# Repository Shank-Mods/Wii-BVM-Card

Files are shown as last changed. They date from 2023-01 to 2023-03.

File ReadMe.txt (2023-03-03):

These are the files I used to create the RVL-129X, a Wii on a BVM card. It is based on Martin's card. This project is essentially me craming his circuit into the corner, and adding pads to 1: solder the controller ports to and 2: bolt the Wii on. Consult his github for more info on the capabilities of the card portion of this project, as well as the software to program the Arduino.

Major Credits to Martin. Heres his github. He was awesome and super helpful. Could not have done this without him. Again, I just copied his homework and bolted a Wii to it. 
https://github.com/skumlos/bkm-129x-simple

It was a quick and dirty project not originally intended for public release. I am releaseing the files as is due to popular demand. It is cluttered, unoptimized, and made for my specific circumstances and my available parts. Sorry in advance.

Follow the Definitive Wii trimming gudie for information on how to trim and run the Wii. Standard trim. Run YPbPr and audio through shielded wire to the marked pads. SH is ground for shielding. Connect Controller lines to controller pads. 4 Layer Wii highly recommended. Leave the 1.8v LDO on the Wii. Ensure your Wii's settings have the resolution set to 480i if your PVMs are 15khz only. If your system is in 480p mode, you can disconnect the 3.3v-to-mode connection so set the system to composite and svideo mode, and run composite or luma to the Y line on the card for a usable black and white 15khz image that will let you navigate menus. 

The 129x card cannot pass audio through the slot, so audio comes out a 3.5mm jack and into the RCA jacks on the back. 

For voltage regulators, I purchased and bolted on an RVL-PSU. It contains all the voltage regulator rails the Wii needs. It is open source. You can assemble one yourself, use the open source design to integrate it onto this PCB, buy an RVL-PSU from CrazyGadget on the Bitbuilt forums, or design your own regulators if you are a pro. Do not use generic chinese voltage regulator boards, their power is not clean and will cause issues.

I included overkill voltage protection for every voltage rail of every controller port. This is because I plan to take it to Melee tournaments. The competitive Melee conroller modding scene has a huge problem with design and quality control of aftermarket and modded controllers. Many systems at tournaments have destroyed components caused by controllers overdrawing the voltage rails. These components are overkill, expensive, and tedious to solder. If these circumstances are not relevant to you, you can omit these components placed by the controller ports, and instead run 3.3v and 5v directly to the 3.3v and 5v pins of the controller ports with wires. 

Near the solder pads for the gamecube controller data wires are some diodes and filters. These are harvested from the lines connected to the data lines on the Wii motherboard. Diodes are for extra ESD protection. Filters can probably be jumpered over, but probably not best practice.

Resistors R2, R3, R4 and R5, along with R14, R15, R16 and R17 are not populated on this board. Csync pad is not used.

For screws I used the silver screws inside the wii, used mostly on the EMI shield.

For the fan and heatsink my usual setup: 35mm x 35mm x 7mm fan with 35mm x 35mm x 7mm heatsink, along with a 35x70mm copper plate. This setup has become the go-to in the portablizing community, and is used on many portables like the G-Wii. Use thermal paste between heatsink and copper plate. Use thermal pad between CPU/GPU and copper plate.

I didnt really plan where to put the USB port. I used a USB to micro SD card adapter, and mounted it to a GCC controller port with double sided foam adhesive tape. 

Theres an LDO (U5) that I didn't include on BOM because the replacement I purchased had a different pinout. I had to bodge it, but I added a jumper in case your LDO has that pinout. Check his github for specs on that part.

Included are 2 STLs that need to be printed. One is for mounting the Wii and the cooling system to the board. The other is the back plate. The back plate has 2 versions. V2 is the one I used. The extrusions for the screws are a little flimsy, so i made V3 to strengthen them. It should work and be stronger, but I never tested it so I included both. All 3d printed parts are mounted with silver scews from the Wii.

Order PCB with 1.6mm thickness. Its a 2 layer board, nothing special.

If you use this project, please credit me. Would love to see what people make with this. If you plan to monetize, please contact me.  

Troubleshooting tips I wish I knew:

Arduino must be programmed using the header. It WILL NOT WORK if programmed through the USB port on the arduino. 

Make sure U2 is being powered by U5 regulator. Different LDOs in that package have different pinouts. 

You can troubleshoot the signal chain by taking the Luma signal and skipping U2 and U1

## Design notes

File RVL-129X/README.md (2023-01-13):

A simplified version of the BKM-129X compatible board.

Should be able to be created at $25-30, with the ADG1611 being the most expensive component.

This requires an Arduino Nano v3 loaded with the latest BKM-129X-MCU code from https://github.com/skumlos/bkm-129x-mcu

For more information go to https://immerhax.com/?p=422

You are welcome to clone, produce and sell hardware based on this. Please keep changes and so on open source.

Cool kids give credit where due.

Thanks goes out to Nick Carney and Bob from RetroRGB for rigorious testing!

--------

Compatibility list and tested consoles (including issues):

PVM-9L2
- SNES (US region, CSYNC)
- Mega Drive 2 (EU region, 60 Hz modded with DFO for "true" 60 Hz, CSYNC)
- Master System 1 (EU region, 60 Hz modded with DFO for "true" 60 Hz, CSYNC)
- PC-Engine (White, with THS7374 external RGB amp, CSYNC)

BVM-D14
- Genesis 1 (60 Hz, CSYNC)

BVM-D9
- Nomad (60 Hz, Triple bypass modded, CSYNC)
- SNES (US region, CSYNC)
- Master System (60 Hz, sync issues like original 129X)
- TurboGrafx/PC-Engine (60 Hz, sync issues like original 129X)

---------

Board revision history:

D: Fix THS7374 filter bypass, move to Kicad 5

C: Rearranged some components for nicer layout

B: Added R29, R30, R31 to compensate for overbrightness

A: Changed R9 to 0 Ohm / jumper

---------

Copyright © 2020 Martin Hejnfelt <martin@hejnfelt.com>
This work is free. You can redistribute it and/or modify it under the
terms of the Do What The Fuck You Want To Public License, Version 2,
as published by Sam Hocevar. See the LICENSE file for more details.

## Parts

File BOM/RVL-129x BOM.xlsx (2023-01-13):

Resistors | Minimum | I ordered this many
75 ohm 1% 0603 | 4 | 20 | CR0603-FX-75R0ELF | https://www.mouser.com/ProductDetail/Bourns/CR0603-FX-75R0ELF?qs=Ody%252BWaR0NcEE9MIPBByqfg%3D%3D
100 ohm 0603 | 4 | 20 | CR0603-FX-1000ELF | https://www.mouser.com/ProductDetail/Bourns/CR0603-FX-1000ELF?qs=K5ddiUFZPT7prY7pGcr1LQ%3D%3D
150 ohm 1% 0603 | 7 | 20 | CR0603-FX-1500ELF | https://www.mouser.com/ProductDetail/Bourns/CR0603-FX-1500ELF?qs=e7cxVwPieupBDLrUX3Cc4g%3D%3D
4.7k 0603 | 2 | 20 | CR0603-FX-4701ELF | https://www.mouser.com/ProductDetail/Bourns/CR0603-FX-4701ELF?qs=CCIlxZRRv7jGwxSydcgiTA%3D%3D
10k 0603 | 4 | 20 | CR0603-FX-1002ELF | https://www.mouser.com/ProductDetail/Bourns/CR0603-FX-1002ELF?qs=K5ddiUFZPT6XHG0dQH96QA%3D%3D
100k 0603 | 5 | 20 | CR0603-FX-1003ELF | https://www.mouser.com/ProductDetail/Bourns/CR0603-FX-1003ELF?qs=K5ddiUFZPT49r0RoKWcKqg%3D%3D
20k | 8 | 20 | CR0603-FX-2002ELF | https://www.mouser.com/ProductDetail/Bourns/CR0603-FX-2002ELF?qs=zx2075yZkZIvZj%252BMy%2F3LPw%3D%3D
210k 0603 | 8 | 20 | CR0603-FX-2103ELF | https://www.mouser.com/ProductDetail/Bourns/CR0603-FX-2103ELF?qs=zx2075yZkZKSM3nxee360w%3D%3D
Capacitors
0.1uf 0805 | 9 | 12 | C0805C104K5RAC7411 | https://www.mouser.com/ProductDetail/KEMET/C0805C104K5RAC7411
1uf 0805 | 1 | 2 | 08055C105KAT4A | https://www.mouser.com/ProductDetail/KYOCERA-AVX/08055C105KAT4A
2.2uf 0805 | 1 | 2 | VJ0805V225MXJTW1BC | https://www.mouser.com/ProductDetail/Vishay-Vitramon/VJ0805V225MXJTW1BC
100uf 6.3x5.3,3 package | 3 | 5 | AVES107M16D16T-F | https://www.mouser.com/ProductDetail/Cornell-Dubilier-CDE/AVES107M16D16T-F
0.1uf 0603 (more than 5v) | 8 | 10 | C0603C104K5RAC3121 | https://www.mouser.com/ProductDetail/KEMET/C0603C104K5RAC3121
10uf 0603 (more than 5v) | 8 | 10 | 06036D106MAT2A | https://www.mouser.com/ProductDetail/KYOCERA-AVX/06036D106MAT2A?qs=SnLCPPi%2FUkQWQ97wPZ%2F8XA%3D%3D
ICs
THS7374 TSSOP-14_4.4x5mm_Pitch0.65mm | 1 | 2 | THS7374IPWR | https://www.mouser.com/ProductDetail/Texas-Instruments/THS7374IPWR?qs=qU0TI%2FZyA%252BxCw%252BZ%2FnXjpBw%3D%3D
ADG1611 TSSOP-16_4.4x5mm_Pitch0.65mm | 1 | 1 | DG1411EEQ-T1-GE4 | https://www.mouser.com/ProductDetail/Vishay-Siliconix/DG1411EEQ-T1-GE4?qs=AQlKX63v8RtOlhgumHRmnQ%3D%3D
74LVC125 TSSOP-14_4.4x5mm_Pitch0.65mm | 1 | 2 | 771-74LVC125APW-T | https://www.mouser.com/ProductDetail/Nexperia/74LVC125APW118?qs=me8TqzrmIYV8VAZOS5KVLw%3D%3D
DTC144EKA SC-59 | 1 | 3 | DTC144EKAT146 | https://www.mouser.com/ProductDetail/ROHM-Semiconductor/DTC144EKAT146?qs=4kLU8WoGk0s6Af1cWyUglg%3D%3D
TPS25221DRVT | 8 | 10 | TPS25221DRVT | https://www.mouser.com/ProductDetail/Texas-Instruments/TPS25221DRVT?qs=55YtniHzbhC2wJe7VYvGRA%3D%3D
Connector
PCN10A-64P-2.54DS(72) | 1 | 1 | PCN10A-64P-2.54DS(72) | https://www.mouser.com/ProductDetail/Hirose-Connector/PCN10A-64P-2.54DS72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
SJ-3524-SMT-TR | 1 | 2 | SJ-3524-SMT-TR
Other
Arduino Nano | 1 |  | What Martin's Github Says
*Yellow lines are for controller protection circuitry

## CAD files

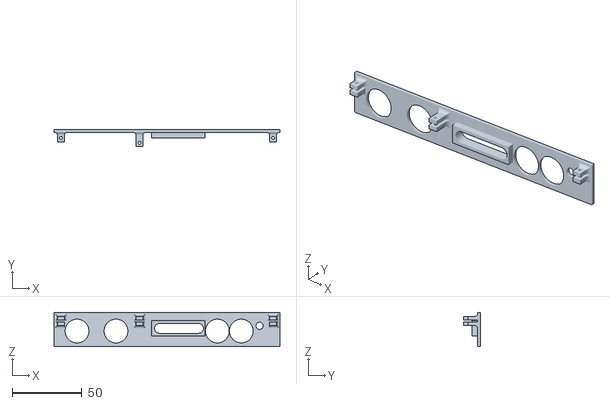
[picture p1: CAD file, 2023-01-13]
STLs/RVL-129xPlate v2 (tested).stl
161.5 x 12.0 x 24.5

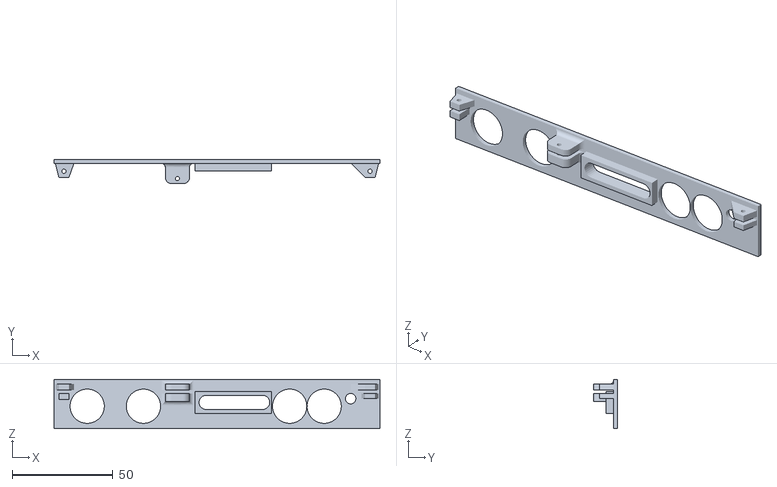
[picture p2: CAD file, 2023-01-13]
STLs/RVL-129xPlate v3 (improved but untested).stl
161.5 x 12.0 x 24.5

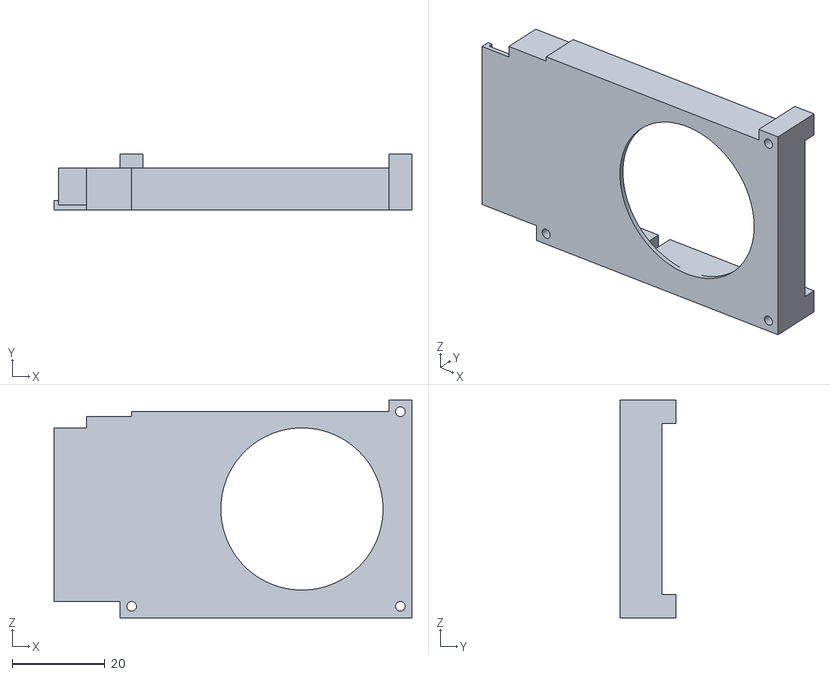
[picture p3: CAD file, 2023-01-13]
STLs/RVL129x-CoolingBracket_v2.stl
77.2 x 12.0 x 47.0

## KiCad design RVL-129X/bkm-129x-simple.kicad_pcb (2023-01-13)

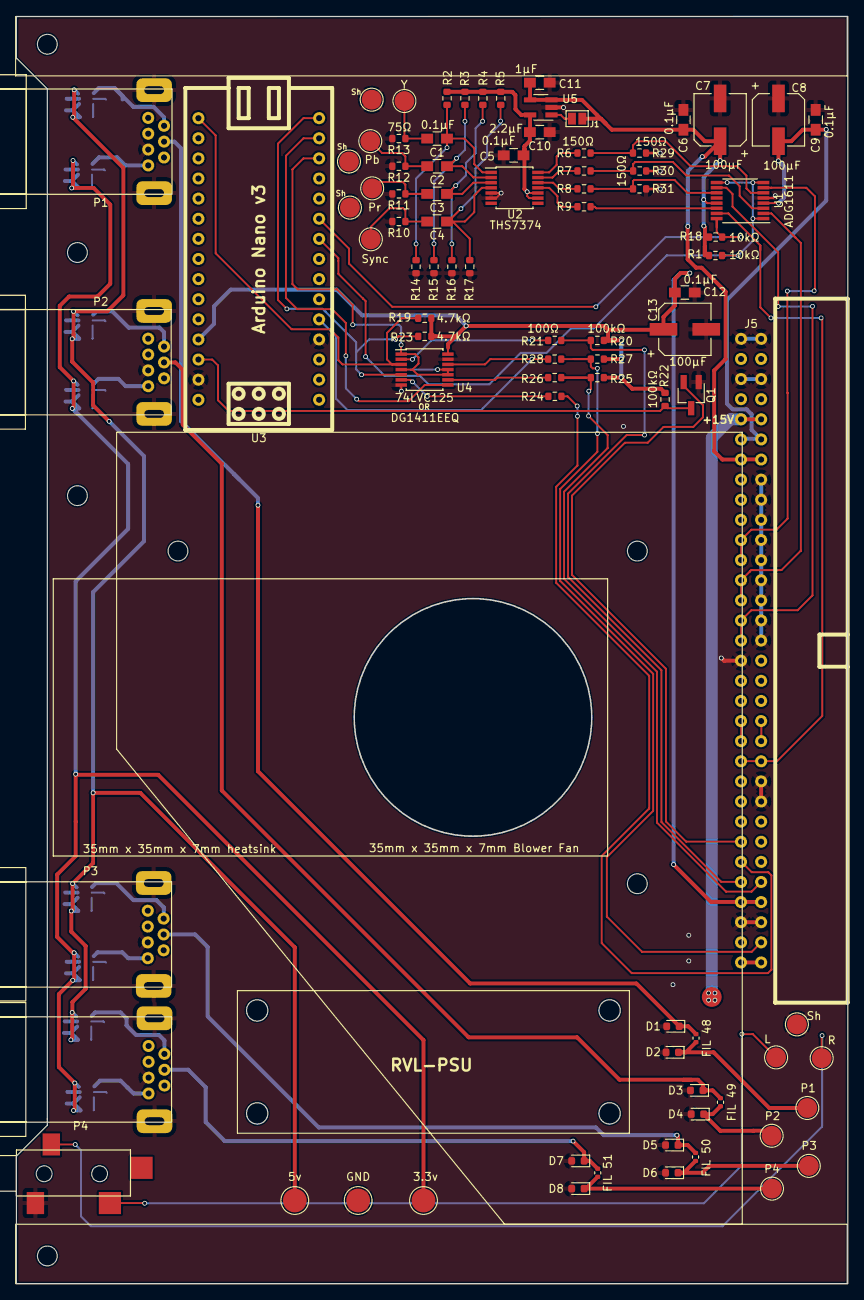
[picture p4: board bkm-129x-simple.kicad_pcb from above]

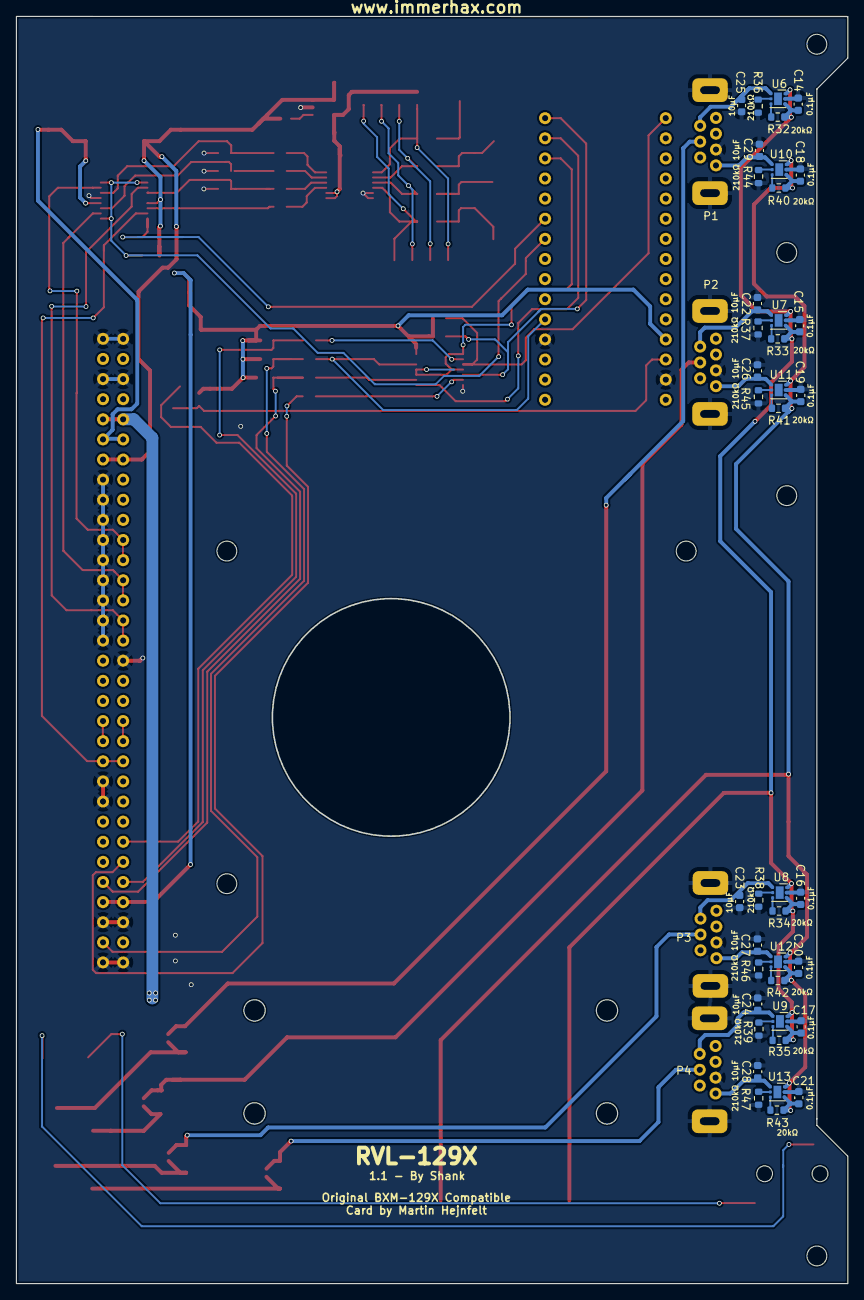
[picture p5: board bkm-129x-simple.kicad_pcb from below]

Board: 2 copper layers, 105.0 x 160.0 mm, 124 parts (40 on the bottom side), 71 nets.

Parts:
C1, C2, C3, C4, C5, C6, C9, C12: 0.1uF; C_0805_HandSoldering
C7, C8, C13: 100uF; CP_Elec_6.3x5.3
C10: 2.2uF; C_0805_HandSoldering
C11: 1uF; C_0805_HandSoldering
C14, C15, C16, C17, C18, C19, C20, C21, C22, C23, C24, C25, C26, C27, C28, C29: C; C_0603_1608Metric
CN1, CN2: GC_Ports; GCC Ports
D1, D2, D3, D4, D5, D6, D7, D8: D; D_0603_1608Metric
J1: SolderJumper-2_P1.3mm_Open_Pad1.0x1.5mm
J5: Conn_02x32_Row_Letter_Last; DIN-41612-64P
Q1: DTC144EKA; SC-59_Handsoldering
R1, R18: 10K; R_0603_1608Metric
R2, R3, R4, R5, R14, R15, R16, R17, R32, R33, R34, R35, R36, R37, R38, R39, R40, R41, R42, R43, R44, R45, R46, R47: R; R_0603_1608Metric
R6, R7, R8, R29, R30, R31: 150R; R_0603_1608Metric
R9: 0R; R_0603_1608Metric
R10, R11, R12, R13: 75R; R_0603_1608Metric
R19, R23: 4K7; R_0603_1608Metric
R20, R22, R25, R27: 100K; R_0603_1608Metric
R21, R24, R26, R28: 100R; R_0603_1608Metric
R48, R49, R50, R51: R; R_0402_1005Metric
TP1, TP2, TP3: TestPoint; TestPoint_Pad_D3.0mm
TP4, TP5, TP6, TP7, TP8, TP9, TP10, TP11, TP12, TP13, TP14, TP15, TP16, TP17: TestPoint; TestPoint_Pad_D2.5mm
U1: ADG1611; TSSOP-16_4.4x5mm_Pitch0.65mm
U2: THS7374; TSSOP-14_4.4x5mm_Pitch0.65mm
U3: arduino-nano-v3
U4: 74LVC125; TSSOP-14_4.4x5mm_Pitch0.65mm
U5: MIC3490-3.3; SOT-23-5_HandSoldering
U6, U7, U8, U9, U10, U11, U12, U13: TPS25221; WSON-6-1EP_2x2mm_P0.65mm_EP1x1.6mm
U14: PWP2_HeadphoneJackWithSwitch; HPJack

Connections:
3V3-P1: C29.1, CN1.7A (3.3v), U10.1 (OUT)
3V3-P2: C26.1, CN1.7B (3.3v), U11.1 (OUT)
3V3-P3: C27.1, CN2.7A (3.3v), U12.1 (OUT)
3V3-P4: C28.1, CN2.7B (3.3v), U13.1 (OUT)
3V3-PSU: C18.1, C19.1, C20.1, C21.1, R40.2, R41.2, R42.2, R43.2, TP1.1, U10.4 (EN), U10.6 (IN), U11.4 (EN), U11.6 (IN), U12.4 (EN), U12.6 (IN), U13.4 (EN), U13.6 (IN)
5V-P1: C25.1, CN1.1A (5v), U6.1 (OUT)
5V-P2: C22.1, CN1.1B (5v), U7.1 (OUT)
5V-P3: C23.1, CN2.1A (5v), U8.1 (OUT)
5V-P4: C24.1, CN2.1B (5v), U9.1 (OUT)
5V-PSU: C14.1, C15.1, C16.1, C17.1, R32.2, R33.2, R34.2, R35.2, TP2.1, U6.4 (EN), U6.6 (IN), U7.4 (EN), U7.6 (IN), U8.4 (EN), U8.6 (IN), U9.4 (EN), U9.6 (IN)
+3V3: C5.1, C10.1, R2.1, R3.1, R4.1, R5.1, U2.9 (BYPASS), U2.10 (VCC), U5.5 (VOUT)
+5VD: C12.1, C13.1, R19.2, R20.2, R22.1, R23.2, R25.2, R27.2, U3.27 (5V), U4.14 (VCC)
/MCU_SCK: R19.1, U3.16 (17/PB5/PCINT5/SCK), U4.3 (O)
/MCU_SLOT_ID: R28.1, U3.5 (32/PD2/INT0/PCINT18), U4.12 (D)
/MOSI: R25.1, R26.2
/SCLK: R20.1, R21.2
/SLOT_ID: R27.1, R28.2
/~MCU_RESET: Q1.3 (C), R22.2, U3.28 (29/PC6/RST/PCINT14)
GCC-P1: CN1.2A (DA), D1.1 (K), R48.2
GCC-P1-Pad: D2.1 (K), R48.1, TP4.1
GCC-P2: CN1.2B (DA), D3.1 (K), R49.2
GCC-P2-Pad: D4.1 (K), R49.1, TP5.1
GCC-P3: CN2.2A (DA), D5.1 (K), R50.2
GCC-P3-Pad: D6.1 (K), R50.1, TP6.1
GCC-P4: CN2.2B (DA), D7.1 (K), R51.2
GCC-P4-Pad: D8.1 (K), R51.1, TP7.1
GND-PSU: C5.2, C6.2, C7.2, C8.1, C9.2, C10.2, C11.1, C12.2, C13.2, C14.2, C15.2, C16.2, C17.2, C18.2, C19.2, C20.2, C21.2, C22.2, C23.2, C24.2, C25.2, C26.2, C27.2, C28.2, C29.2, CN1.6A (GND), CN1.6B (GND), CN1.8 (Shield), CN2.6A (GND), CN2.6B (GND), CN2.8 (Shield), D1.2 (A), D2.2 (A), D3.2 (A), D4.2 (A), D5.2 (A), D6.2 (A), D7.2 (A), D8.2 (A), J5.1a, J5.1b, J5.3a, J5.3b, J5.8a, J5.9a, J5.10a, J5.11a, J5.12a, J5.13a, J5.14a, J5.15a, J5.16a, J5.17b, J5.23a, J5.24a, J5.30a, J5.30b, J5.32a, J5.32b, Q1.1 (E), R10.2, R11.2, R12.2, R13.2, R14.2, R15.2, R16.2, R17.2, R29.2, R30.2, R31.2, R36.2, R37.2, R38.2, R39.2, R44.2, R45.2, R46.2, R47.2, TP3.1, TP8.1, TP9.1, TP10.1, TP11.1, U1.5 (GND), U2.5 (GND), U2.6 (DISABLE), U3.4 (GND), U3.29 (GND), U4.7 (GND), U4.13 (E), U5.2 (GND), U6.5 (GND), U7.5 (GND), U8.5 (GND), U9.5 (GND), U10.5 (GND), U11.5 (GND), U12.5 (GND), U13.5 (GND), U14.1 (Sleeve/Shield)
unnamed: C1.1, R2.2, R14.1, U2.1 (CH1_IN)
unnamed: C1.2, R13.1, TP12.1
unnamed: C2.1, R3.2, R15.1, U2.2 (CH2_IN)
unnamed: C2.2, R12.1, TP13.1
unnamed: C3.1, R4.2, R16.1, U2.3 (CH3_IN)
unnamed: C3.2, R11.1, TP14.1
unnamed: C4.1, R5.2, R17.1, U2.4 (CH4_IN)
unnamed: C4.2, R10.1, TP15.1
unnamed: R6.2, U2.14 (CH1_OUT)
unnamed: R7.2, U2.13 (CH2_OUT)
unnamed: R8.2, U2.12 (CH3_OUT)
unnamed: R9.1, U1.14 (S)
unnamed: R9.2, U2.11 (CH4_OUT)
unnamed: R21.1, U4.2 (D)
unnamed: R23.1, U3.15 (16/PB4/PCINT4/MISO), U4.5 (D)
unnamed: R24.1, U4.6 (O)
unnamed: R26.1, U4.9 (D)
unnamed: R6.1, R29.1, U1.6 (S)
unnamed: R7.1, R30.1, U1.3 (S)
unnamed: R8.1, R31.1, U1.11 (S)
unnamed: R32.1, U6.3 (FAULT)
unnamed: R33.1, U7.3 (FAULT)
unnamed: R34.1, U8.3 (FAULT)
unnamed: R35.1, U9.3 (FAULT)
unnamed: R36.1, U6.2 (ILIM)
unnamed: R37.1, U7.2 (ILIM)
unnamed: R38.1, U8.2 (ILIM)
unnamed: R39.1, U9.2 (ILIM)
unnamed: R40.1, U10.3 (FAULT)
unnamed: R41.1, U11.3 (FAULT)
unnamed: R43.1, U13.3 (FAULT)
unnamed: R44.1, U10.2 (ILIM)
unnamed: R45.1, U11.2 (ILIM)
unnamed: R46.1, U12.2 (ILIM)
unnamed: R47.1, U13.2 (ILIM)
unnamed: TP16.1, U14.2 (Tip/Left)
unnamed: TP17.1, U14.3 (Ring/Right)
unnamed: U3.13 (14/PB2/OC1B/PCINT2/~SS), U4.1 (E), U4.4 (E), U4.10 (E), U4.11 (O)
unnamed: U3.14 (15/PB3/OC2/PCINT3/MOSI), U4.8 (O)
unnamed: R42.1, U12.3 (FAULT)
VDD: C6.1, C7.1, C11.2, J1.2, J5.7a, J5.7b, R1.2, R18.1, U1.13 (VDD), U5.3 (EN), U5.4 (VIN)
VSS: C8.2, C9.1, J5.6a, J5.6b, U1.4 (VSS)
~BX_OE: R1.1, U1.1 (IN), U1.8 (IN), U1.9 (IN), U3.9 (10/PD6/AIN0/PCINT22/OC0A)
~EXT_SYNC_OE: R18.2, U1.16 (IN), U3.10 (11/PD7/AIN1/PCINT23)
